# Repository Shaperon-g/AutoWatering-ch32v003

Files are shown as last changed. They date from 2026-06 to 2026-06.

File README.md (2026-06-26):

# AutoWatering
Простой проект на базе чипа ch32v003j4m6, без HAL, только на регистрах.
Поливалка цветка, использует Arduino модуль влажности почвы и какую-то помпу.

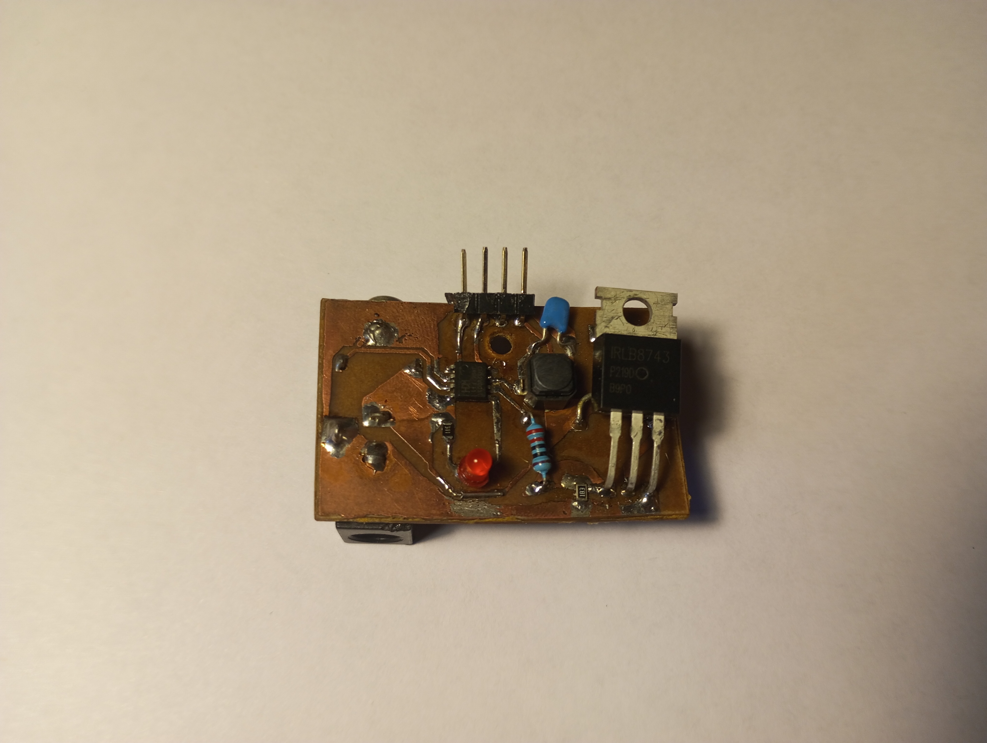
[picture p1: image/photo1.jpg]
фоточка


# Управление
На плате есть кнопка, светодиод, и разъемы для датчика влажнности почвы и насоса с дополнительной обвязкой.

При подклюцении питания плата сначала 5 секунд "тупит" (это надо для программирования), а потом моргает один раз светодиодом и проверяет влажность почвы, и если она суше сохраненного значения, то включает помпу на заданное время (по умолчанию 2 секунды, можете изменить в main.cpp:AWTR_WATERING_TIME). 
То же самое МК делает, если быстро нажать кнопку.

Если удержать кнопку на протяжении 2 - 3 секунд, то чип сохраняет значение датчика к себе в flash память в качестве граничного между сухой землей и влажной. После этого должен моргнуть светодиод **дважды**.

Ещё на протяжении всей работы МК отправляет в UART (4800 baudrate) сообщения с информацией, что он сейчас делает.
И если зажать кнопку дольше 5 секунд, то программа уходит в цикл, где передает значение датчика в UART и моргает светодиодом раз в секунду.

# Железо
Собирал я проект из того, что было под ногами, поэтому в моей реализации вы можете увидеть разъём Mini-Jack ля соединения датчика и платы (ну а почему бы и нет). Все компоненты здесь избыточны, поэтому подбирайте что-то своё.
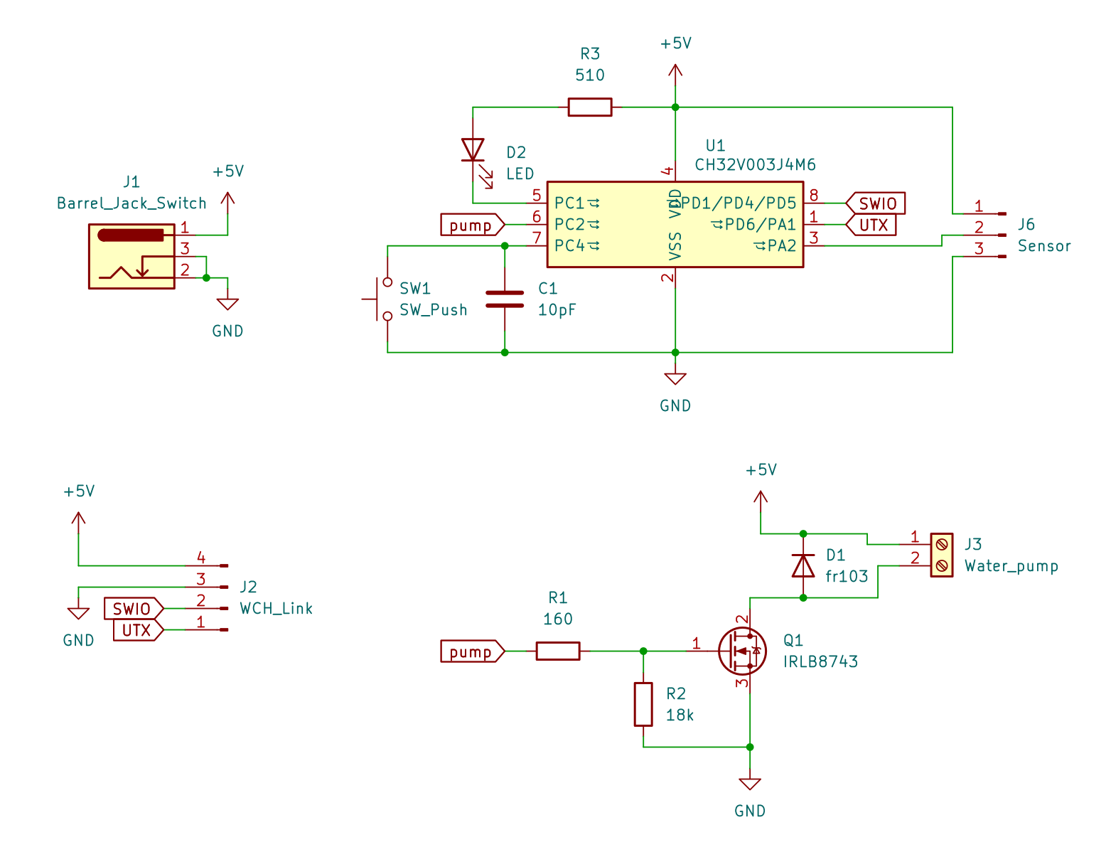
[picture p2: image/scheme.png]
здесь должна быть схема


# Сборка
0. Сачала в PATH системы должны быть добавлены папки с GCC от WCH и OpenOCD, или вручную прописать их в 
Makefile (ещё нужен make).
1. Cборка из исходников (если ничего не меняли, то можно пропустить)
    ```
    make build
    ```
2. Подключить WCH-LinkE и прошить.
    ```
    make load
    ```

Если чип уже был прошит этим кодом, то надо успеть в первые 5 секунд его работы. Просто я решил установить очень низкое тактирование, чтобы МК мог находиться в режиме сна более 24 часов, но как оказалось, для SDI нужна частота более 1 мегагерца, поэтому перевод к низкому тактированию происходит спустя 5 секунд. Поэтому же и частота UART должна быть достаточно низкой.

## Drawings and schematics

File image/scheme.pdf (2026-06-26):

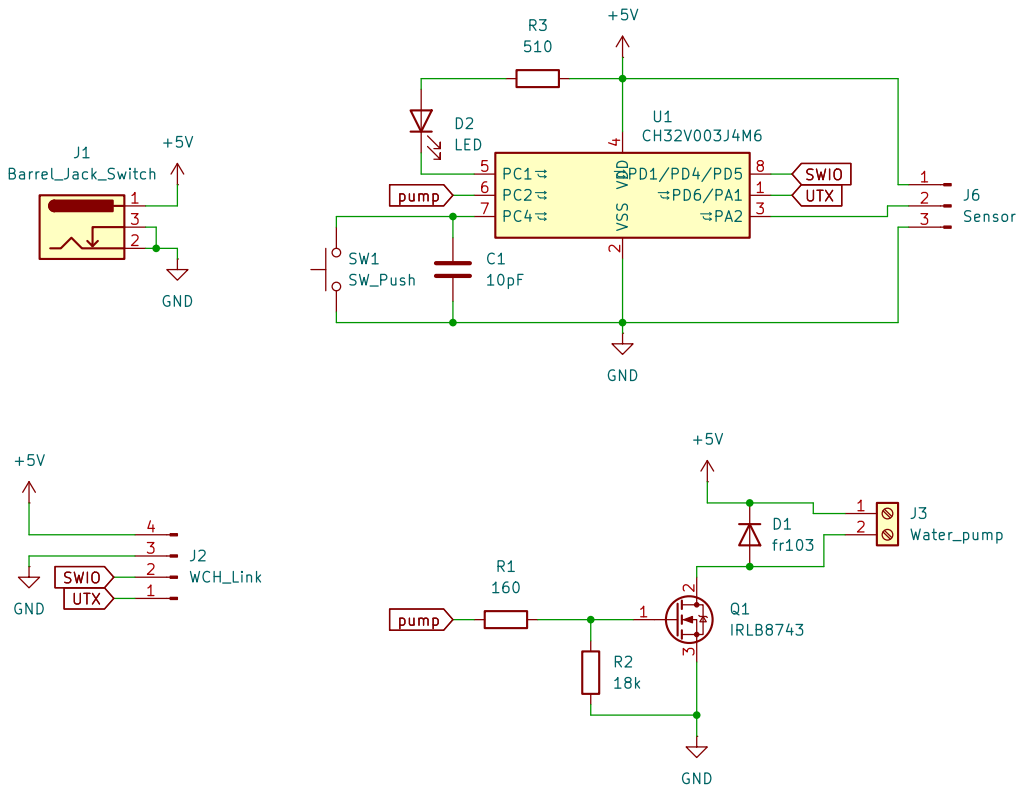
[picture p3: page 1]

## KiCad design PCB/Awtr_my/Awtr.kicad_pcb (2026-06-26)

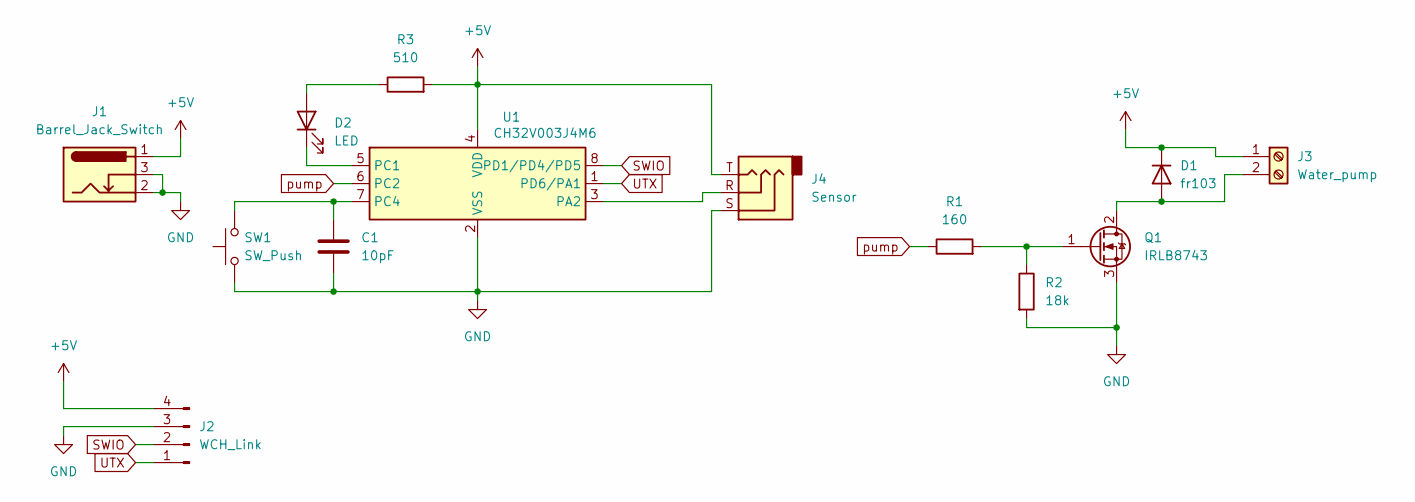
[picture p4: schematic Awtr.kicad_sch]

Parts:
C1: 10pF; C_Disc_D5.0mm_W2.5mm_P5.00mm
D1: fr103; D_DO-41_SOD81_P10.16mm_Horizontal
D2: LED; LED_D5.0mm
J1: Barrel_Jack_Switch; BarrelJack_Horizontal
J2: WCH_Link; PinHeader_1x04_P2.54mm_Vertical
J3: Water_pump; JST_NV_B02P-NV_1x02_P5.00mm_Vertical
J4: Sensor; Jack_3.5mm_CUI_SJ1-3523N_Horizontal
Q1: IRLB8743; TO-220-3_Vertical
R1: 160; R_Axial_DIN0207_L6.3mm_D2.5mm_P10.16mm_Horizontal
R2: 18k; R_0805_2012Metric_Pad1.20x1.40mm_HandSolder
R3: 510; R_0805_2012Metric_Pad1.20x1.40mm_HandSolder
SW1: SW_Push; SW_Push_1TS009xxxx-xxxx-xxxx_6x6x5mm
U1: CH32V003J4M6; SOIC-8_3.9x4.9mm_P1.27mm

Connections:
+5V: D1.1 (K), J1.1, J2.4, J3.1, J4.T, R3.2, U1.4 (VDD)
GND: C1.2, J1.2, J1.3, J2.3, J4.S, Q1.3 (S), R2.2, SW1.1, U1.2 (VSS)
unnamed: D1.2 (A), J3.2, Q1.2 (D)
unnamed: D2.2 (A), R3.1
unnamed: D2.1 (K), U1.5 (PC1)
unnamed: Q1.1 (G), R1.2, R2.1
unnamed: J4.R, U1.3 (PA2)
unnamed: C1.1, SW1.2, U1.7 (PC4)
SWIO: J2.2, U1.8 (PD1/PD4/PD5)
UTX: J2.1, U1.1 (PD6/PA1)
pump: R1.1, U1.6 (PC2)

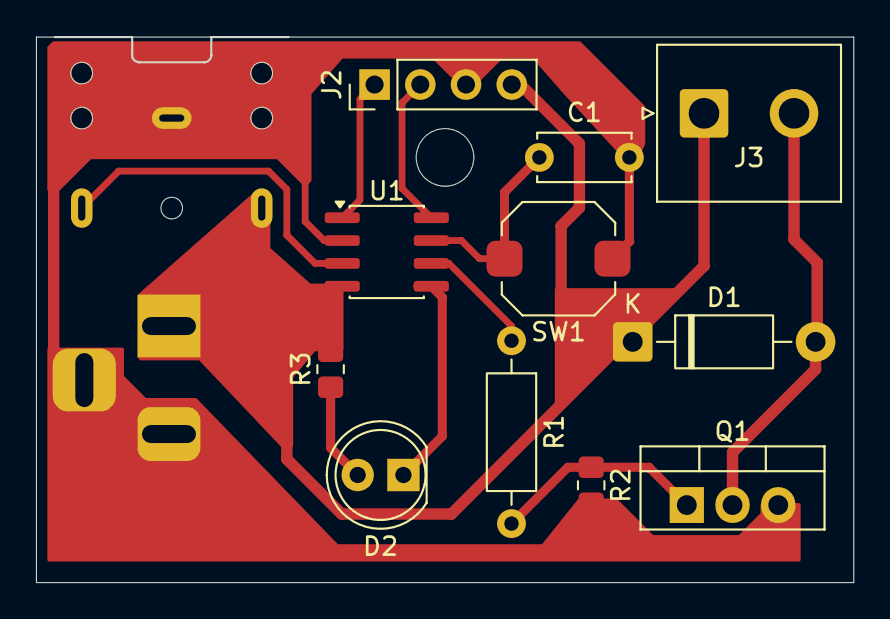
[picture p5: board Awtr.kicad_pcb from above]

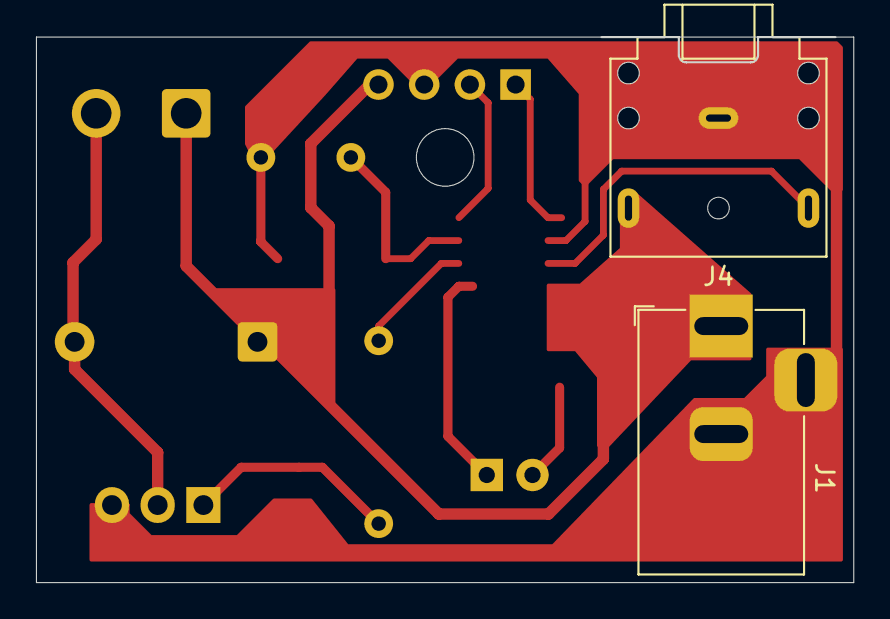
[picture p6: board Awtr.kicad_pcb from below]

Board: 2 copper layers, 45.4 x 30.3 mm, 13 parts (2 on the bottom side), 11 nets.

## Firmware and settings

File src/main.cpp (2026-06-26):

/* configurations */
#ifndef AWTR_UPDATE_TIME
#define AWTR_UPDATE_TIME 12   // [1 - 40 hours]
#endif
#ifndef AWTR_WATERING_DUR
#define AWTR_WATERING_DUR 2000   // [ms]
#endif

/* clock preferences. Don't change thoughtlessly! */
#define F_HBCLK 187500
#define UART_BAUDRATE 4800

#define MS_TO_TICKS(ms) ((uint32_t)(ms) * (F_HBCLK / 8000))
#define TIMER_UPDATE MS_TO_TICKS(AWTR_UPDATE_TIME * 3600 * 1000)

/* Includes */
#include <ch32v00x.h>
#include <uart.h>
#include "GPIO.h"
#include "ASCII_fun.h"

/* Global Variable */
enum awtr_state_t {
	waiting,
	click,
	hold,
	long_hold,
	toSleep,
};
volatile awtr_state_t awtr_state;
uint8_t sens_val = 0;
uint8_t sens_val_border = 50;
#define BORDER ((uint32_t*)0x08003FC0)

uart uart1(USART1, UART_BAUDRATE, F_HBCLK);
uint8_t msg_click_dry[] = "Ground is dry: XXX\n";
uint8_t msg_click_wet[] = "Ground is wet: XXX\n";
uint8_t msg_hold[] = "(X) sens border: XXX\n";
uint8_t msg_lhold[] = "Sensor value: XXX\n";

/* Program */
void delayT(uint32_t val) {       // [val] ~= 0.042 sec
	uint32_t cnt_prev, cnt_cur;
	cnt_prev = SysTick->CNT;
	cnt_cur = SysTick->CNT;
	while(cnt_cur < cnt_prev + val) {
		cnt_cur = SysTick->CNT;
	}
	return;
}

uint8_t flash_get() {
	return *BORDER;
}
uint8_t flash_save(uint8_t data) {
	__disable_irq();
	FLASH->KEYR = 0x45670123;
	FLASH->KEYR = 0xCDEF89AB;
	if(FLASH->CTLR & FLASH_CTLR_LOCK) {
		return 1;
	}
	FLASH->MODEKEYR = 0x45670123;
	FLASH->MODEKEYR = 0xCDEF89AB;
	if(FLASH->CTLR & FLASH_CTLR_FLOCK) {
		return 1;
	}

	FLASH->CTLR |= FLASH_CTLR_PAGE_ER;
	FLASH->ADDR = 0x08003FC0;
	FLASH->CTLR |= FLASH_CTLR_STRT;
	while(FLASH->STATR & FLASH_STATR_BSY) {;}
	FLASH->CTLR &= ~(FLASH_CTLR_PAGE_ER);

	FLASH->CTLR |= FLASH_CTLR_PAGE_PG;
	FLASH->CTLR |= FLASH_CTLR_BUF_RST;
	while(FLASH->STATR & FLASH_STATR_BSY) {;}
	*BORDER = (uint32_t)data;
	FLASH->CTLR |= FLASH_CTLR_BUF_LOAD;
	while(FLASH->STATR & FLASH_STATR_BSY) {;}
	FLASH->ADDR = 0x08003FC0;
	FLASH->CTLR |= FLASH_CTLR_STRT;
	while(FLASH->STATR & FLASH_STATR_BSY) {;}
	FLASH->CTLR &= ~(FLASH_CTLR_PAGE_PG);
	FLASH->CTLR |= FLASH_CTLR_LOCK;
	if(FLASH->STATR & FLASH_STATR_WRPRTERR) {
		return 1;
	}
	__enable_irq();
	return 0;
}

extern "C"{
void SystemInit() {
	/*RCC*/
	RCC->CFGR0 &= ~(RCC_HPRE | RCC_ADCPRE);
	RCC->CFGR0 |= RCC_HPRE_DIV16 | RCC_ADCPRE_DIV2; //HBCLK = 1.5 MHz
	RCC->APB2PCENR |= RCC_IOPAEN | RCC_IOPCEN | RCC_IOPDEN | 
	                  RCC_ADC1EN | RCC_USART1EN | RCC_AFIOEN;
	
	/*Timer*/
	SysTick->CNT = 0;
	SysTick->CMP = 0xFFFFFFFF;
	SysTick->CTLR = STK_STIE | STK_STRE | STK_STE;
	
	/*GPIO*/
	LED_PORT->CFGLR &= ~(IO_MASK << LED_GPIN);
	LED_PORT->CFGLR |= (IO_OUT_OD | IO_OUT_2M) << LED_GPIN;
	led_off();

	PUMP_PORT->CFGLR &= ~(IO_MASK << PUMP_GPIN);
	PUMP_PORT->CFGLR |= (IO_OUT_PP | IO_OUT_2M) << PUMP_GPIN;

	BTN_PORT->CFGLR &= ~(IO_MASK << BTN_GPIN);
	BTN_PORT->CFGLR |= (IO_IN | IO_IN_PUD) << BTN_GPIN;
	BTN_PORT->BSHR = 1 << btn_pin;  //pull-up
	AFIO->EXTICR |= BTN_EXTI;
	EXTI->INTENR |= 1 << btn_pin;
	EXTI->FTENR |= 1 << btn_pin;
	EXTI->RTENR |= 1 << btn_pin;
	EXTI->INTFR |= 1 << btn_pin;
	EXTI->EVENR |= 1 << btn_pin;

	SENS_PORT->CFGLR &= ~(IO_MASK << SENS_GPIN);
	SENS_PORT->CFGLR |= (IO_IN | IO_IN_AN) << SENS_GPIN;

	UTX_PORT->CFGLR &= ~(IO_MASK << UTX_GPIN);
	UTX_PORT->CFGLR |= (IO_OUT_APP | IO_OUT_10M) << UTX_GPIN;
	AFIO->PCFR1 |= UTX_REMAP;

	/*ADC*/
	ADC1->CTLR1 |= 0;  //Single single-channel mode
	ADC1->CTLR2 |= ADC_ALIGN | ADC_ADON;
	ADC1->SAMPTR2 = 0;
	ADC1->RSQR1 = 0;
	ADC1->RSQR2 = 0;
	ADC1->RSQR3 = SENS_ADC_CHANNEL << 0;

	/* RCC end*/
	delayT(MS_TO_TICKS(5000 * 8)); //for program chip (~ 5 sec)
	RCC->CFGR0 &= ~(RCC_HPRE | RCC_ADCPRE);
	RCC->CFGR0 |= RCC_HPRE_DIV128 | RCC_ADCPRE_DIV2;  //HBCLK = 187.5 kHz
	SysTick->CNT = 0;
	SysTick->CMP = TIMER_UPDATE;
}
}

int main(void)
{
	uint8_t tmp;
	NVIC_EnableIRQ(SysTick_IRQn);
	NVIC_EnableIRQ(USART1_IRQn);
	NVIC_EnableIRQ(EXTI7_0_IRQn);
	NVIC_EnableIRQ(HardFault_IRQn);
	
	__enable_irq();

	uart1.print("UART is work!!! \n");
	sens_val_border = flash_get(); 
	awtr_state = click;
	
	while(1) {
		switch(awtr_state) {
		case waiting:
			uint32_t cnt_prev, cnt_cur;
			cnt_prev = SysTick->CNT;
			cnt_cur = SysTick->CNT;
			while(cnt_cur < cnt_prev + MS_TO_TICKS(10000) && awtr_state == waiting) {
				cnt_cur = SysTick->CNT;
			}
			if(awtr_state == waiting) {
				awtr_state = toSleep;
			}
			break;

		case click:
			led_on();
			delayT(MS_TO_TICKS(10));
			led_off();
			sens_val = sens_get();
			if(sens_val > sens_val_border) {
				__disable_irq();
				pump_on();
				delayT(MS_TO_TICKS(AWTR_WATERING_DUR));
				pump_off();
				__enable_irq();
				intToASCII(sens_val, msg_click_dry + 15, 3);
				uart1.send(msg_click_dry, sizeof(msg_click_dry) - 1);
			}
			else {
				intToASCII(sens_val, msg_click_wet + 15, 3);
				uart1.send(msg_click_wet, sizeof(msg_click_wet) - 1);
			}
			awtr_state = toSleep;
			break;
		case hold:
			led_on();
			delayT(MS_TO_TICKS(10));
			led_off();
			sens_val_border = sens_get();
			tmp = flash_save(sens_val_border);
			sens_val_border = flash_get();
			delayT(MS_TO_TICKS(200));
			led_on();
			intToASCII(tmp, msg_hold + 1, 1);
			intToASCII(sens_val_border, msg_hold + 17, 3);
			uart1.send(msg_hold, sizeof(msg_hold) - 1);
			delayT(MS_TO_TICKS(15));
			led_off();
			awtr_state = toSleep;
			break;
		case long_hold:
			uart1.print("Measurement cycle, click button for exit\n");
			while(awtr_state == long_hold) {
				led_on();
				sens_val = sens_get();
				intToASCII(sens_val, msg_lhold + 14, 3);
				uart1.send(msg_lhold, sizeof(msg_lhold) - 1);
				led_off();
				delayT(MS_TO_TICKS(1000));
			}
			break;

		case toSleep:
			uart1.sync();
			uart1.print("chip fall asleep\n");
			uart1.sync();
			RCC->APB2PCENR &= ~(RCC_IOPARST | RCC_ADC1RST | RCC_USART1RST);
			__WFI();

			RCC->APB2PCENR |= RCC_IOPAEN | RCC_IOPCEN | RCC_IOPDEN | 
	                  RCC_ADC1EN | RCC_USART1EN | RCC_AFIOEN;
			uart1.print("chip wake up \\(^o^)/\n");
			break;
		}
	}
	return 0;
}

/* Interrupts */
extern "C"{
__attribute((interrupt("WCH-Interrupt-fast")))
void USART1_IRQHandler(void) {
    uart1.interruptHandler();
}

__attribute((interrupt("WCH-Interrupt-fast")))
void SysTick_IRQHandler(void) {
	SysTick->SR = 0;
	uart1.print("Timer update\n");
	awtr_state = click;
	return;
}

__attribute((interrupt("WCH-Interrupt-fast")))
void EXTI7_0_IRQHandler(void) {
	EXTI->INTFR |= 1 << btn_pin;
	static uint32_t wait;

	static uint8_t btn_state_last = 0;
	uint8_t btn_state_new = btn_state();
	if(btn_state_new == btn_state_last) {
		return;
	}
	btn_state_last = btn_state_new;

	if(btn_state_new) {
		uart1.print("button was pressed\n");
		wait = SysTick->CNT;
		awtr_state = waiting;
	}
	else {
		uart1.print("button was released\n");
		wait = SysTick->CNT - wait;
		if(wait < MS_TO_TICKS(10)) {
			awtr_state = toSleep;
		}
		else if(wait < MS_TO_TICKS(700)) {
			awtr_state = click;
		}
		else if(wait < MS_TO_TICKS(3000)) {
			awtr_state = hold;
		}
		else {
			awtr_state = long_hold;
		}
	}
	return;
}

__attribute((interrupt("WCH-Interrupt-fast")))
void HardFault_Handler(void) {
	led_on();
	while(1) {;}
}
}

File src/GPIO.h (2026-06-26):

#ifndef GPIO_H_
#define GPIO_H_

#include <ch32v00x.h>

/* for initialization */
#define IO_MASK    0b1111

#define IO_IN      0b0000
#define IO_OUT_10M 0b0001
#define IO_OUT_2M  0b0010
#define IO_OUT_50M 0b0011

#define IO_OUT_PP  0b0000
#define IO_OUT_OD  0b0100
#define IO_OUT_APP 0b1000
#define IO_OUT_AOD 0b1100
#define IO_IN_AN   0b0000
#define IO_IN_FL   0b0100
#define IO_IN_PUD  0b1000

#define IO_P0 0
#define IO_P1 4
#define IO_P2 8
#define IO_P3 12
#define IO_P4 16
#define IO_P5 20
#define IO_P6 24
#define IO_P7 28

/* pinout */
#define LED_PORT GPIOC
#define LED_GPIN IO_P1
enum {led_pin = 1};

#define PUMP_PORT GPIOC
#define PUMP_GPIN IO_P2
enum {pump_pin = 2};

#define BTN_PORT GPIOC
#define BTN_GPIN IO_P4
enum {btn_pin = 4};
#define BTN_EXTI AFIO_EXTICR_EXTI4_PC

#define UTX_PORT GPIOD
#define UTX_GPIN IO_P6  //remap
enum {utx_pin = 6};
#define UTX_REMAP AFIO_PCFR1_USART1_REMAP_REMAP2

#define SENS_PORT GPIOA
#define SENS_GPIN IO_P2
#define SENS_ADC_CHANNEL 0
enum {sens_pin = 2};

/* LED, pump and button */
void led_on();
void led_off();
void pump_on();
void pump_off();
uint8_t btn_state(); // 1 - pressed, 0 - released
uint16_t sens_get();

#endif

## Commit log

2026-06-26 Первый коммит. +tim, btn, uart
    [Awtr.kicad_pcb, Awtr.kicad_sch, wch-riscv.cfg]
2026-06-26 +saving to flash
    [Awtr.kicad_pcb]
2026-06-26 add README
    [Awtr.kicad_pcb, Awtr.kicad_sch]
